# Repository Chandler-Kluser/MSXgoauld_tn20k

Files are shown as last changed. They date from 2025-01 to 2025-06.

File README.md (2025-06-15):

# MSXgoauld_tn20k
MSX Goa'uld board with Tang Nano 20k

Pantallazo
goauld_smd

MSX2+ engine in Z80 socket. It turns one MSX into an MSX2+ by replacing Z80 processor. FPGA in board contains: 
* Z80
* V9958 with hdmi output
* MSX2+ BIOS
* 4MB mapper
* RTC
* PSG through hdmi
* PPI Key Clicks through hdmi
* OPLL through hdmi
* SCC (audio only) through hdmi
* USB Keyboard with [MSX Goa'uld Friend](https://github.com/Chandler-Kluser/msx-goauld-friend)
* Scanlines toggling with [MSX Goa'uld Friend](https://github.com/Chandler-Kluser/msx-goauld-friend)
* On Screen Display (OSD) toggling with [MSX Goa'uld Friend](https://github.com/Chandler-Kluser/msx-goauld-friend)

## How it works
Logic acts on bus control signals so that internal devices inside fpga take priority over external devices. 

Esquema

Mind Revision 2, 4 and 4.1 uses 74LVC245 in U5. Although their technical information tells they require 3.3V to operate, they are also 5V tolerant. This has been tested and considered safe. Check https://github.com/jabadiagm/MSXgoauld_tn20k/issues/15 for more information. Revisions 2, 4 are outdated and kept for reference only. 

## Revision 2 Board

Revision 2 uses SOIC-20 for 74HCT373 and 74LVC245 ICs, which are smaller:



## Revision 4 Board

Revision 4 uses TSSOP-20 ICs, to get an even smaller footprint:


## Revision 4.1 Board

Revision 4.1 is an improvement of Revision 4, with no external regulator and UART Headers to use with [MSX Goa'uld Friend](https://github.com/Chandler-Kluser/msx-goauld-friend)

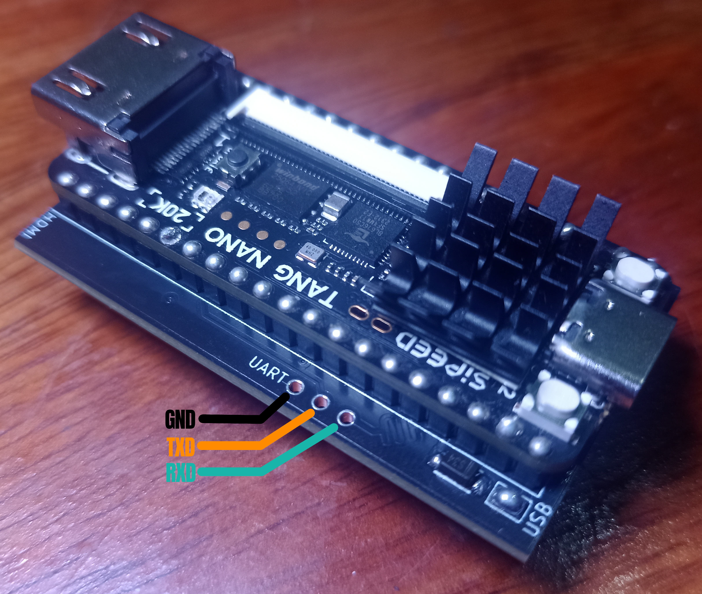
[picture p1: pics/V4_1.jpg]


## Slot map

Slot map

Mapper can be relocated to slots 1, 2, or 3 using config menu.

## Update from previous hardware
* Replace U1, U2 -> 74HC373, U5 -> 74HC245
* Solder a 10K resistor array to data bus lines, pulled up to 5V
Array

## SCC audio
SCC is located in Slot 0-2 to use with sofarun, using these settings:

ext_scc

## Configuration
Config menu is showed pressing g during MSX logo. New improved menu is created by [nataliapc](https://github.com/nataliapc/msx_goauld_settings_menu)

Config

* Enable Mapper: On by default. Disable when having compatibility issues or to use a different mapper
* Mapper Slot: 0 by default. Change to 1-3 to get mapper in a not expanded slot (best compatibility). Physical slot will be disabled
* Slot 1 Ghost SCC: Off by default. Enable to get sound from an SCC cartridge located in slot 1
* Enable Scanlines: On by default. Disable to get a clean hdmi picture
* Save & Exit: store new config and continue, changes in mapper settings will be effective after pressing reset
* Save & Reset: store new config and make software reset, changes will be immediate

## Slots dance
Goa'uld has four internal slots available. As with other modules, internal slots take priority over physical ones. This means that when a device is using internal slot n, then physical slot n is disabled  and any cartridge in that slot will not be detected. 
By default, BIOS and mapper occupy internal slot 0, leaving physical slots 1 to 3 available for cartridges. However, this default layout can cause compatibility issues with some software, such as tape games. 
To resolve these issues, you can move the mapper from expanded slot 0 to one of the non-expanded internal slots (1, 2, or 3). This adjustment can solve many compatibility problems.

## Known issues
* Reset from config menu is not compatible with some hardware. Use physical reset button when possible
* Multimente: shows garbage characters. Move internal mapper to slots 1, 2 or 3
* Tape games fail: move internal mapper to slots 1, 2 or 3
* Noises when loading a rom with sofarun: change sofarun settings to use mapper for that rom
* Carnivore C2 software reset is not compatible with goa'uld

> [!WARNING]
> Not yet fully working on all MSX!
>

### Tips
* Get integrated circuits from trusted sources
* Use a heatsink when possible
* Use turned pins in header to avoid damages in Z80 socket
turned header
* Board is sensitive to dirty electrical contacts, way more than Z80. Keep cartridge & Z80 socket contacts clean
* When soldering headers, start with the inner one (Z80)

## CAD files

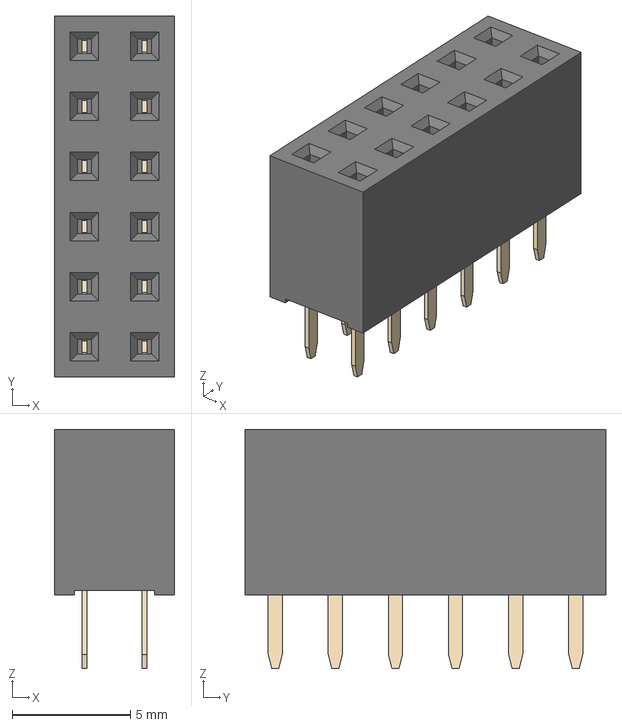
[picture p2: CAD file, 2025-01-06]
kicad/v1_smd/librerias/3D/PinSocket_2x06_P2.54mm_Vertical.step
5.08 x 15.2 x 10.1 mm

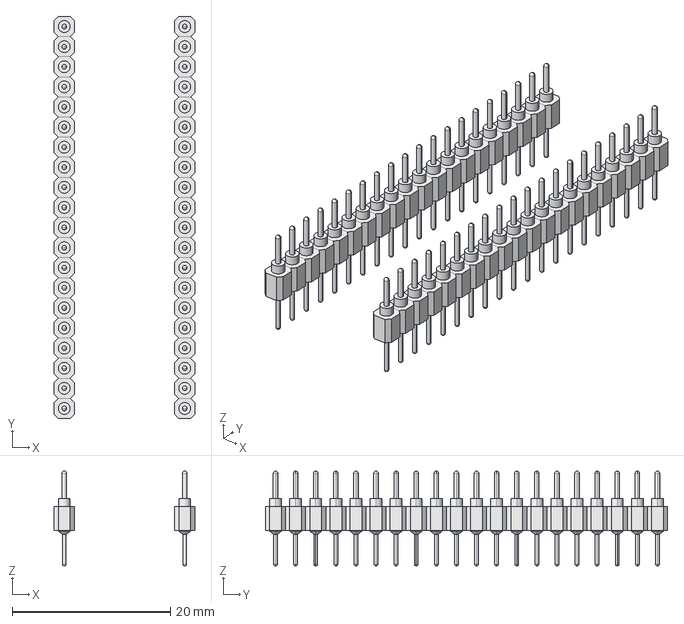
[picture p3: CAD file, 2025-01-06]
kicad/v1_smd/librerias/3D/Z80_PINHEADER.step
17.8 x 50.8 x 12.0 mm
Header-Male-round x 40

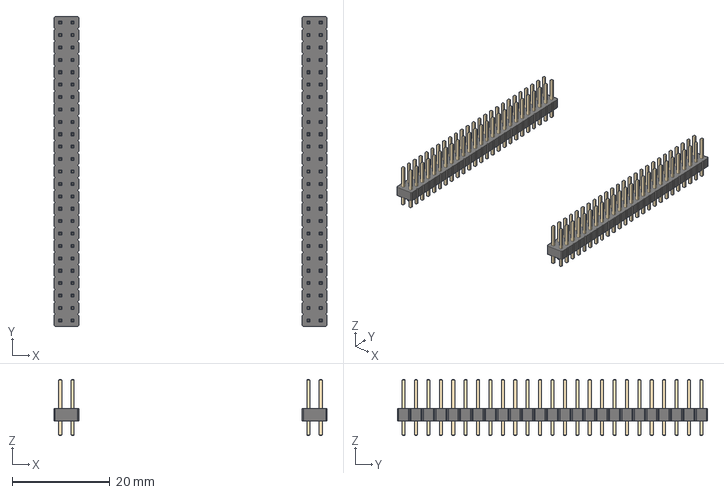
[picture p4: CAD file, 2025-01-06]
kicad/v1_smd/librerias/3D/Qmtech_xc7a15t_35t.step
55.9 x 63.5 x 11.5 mm
PinHeader_2x25_P254mm_Vertical x 2

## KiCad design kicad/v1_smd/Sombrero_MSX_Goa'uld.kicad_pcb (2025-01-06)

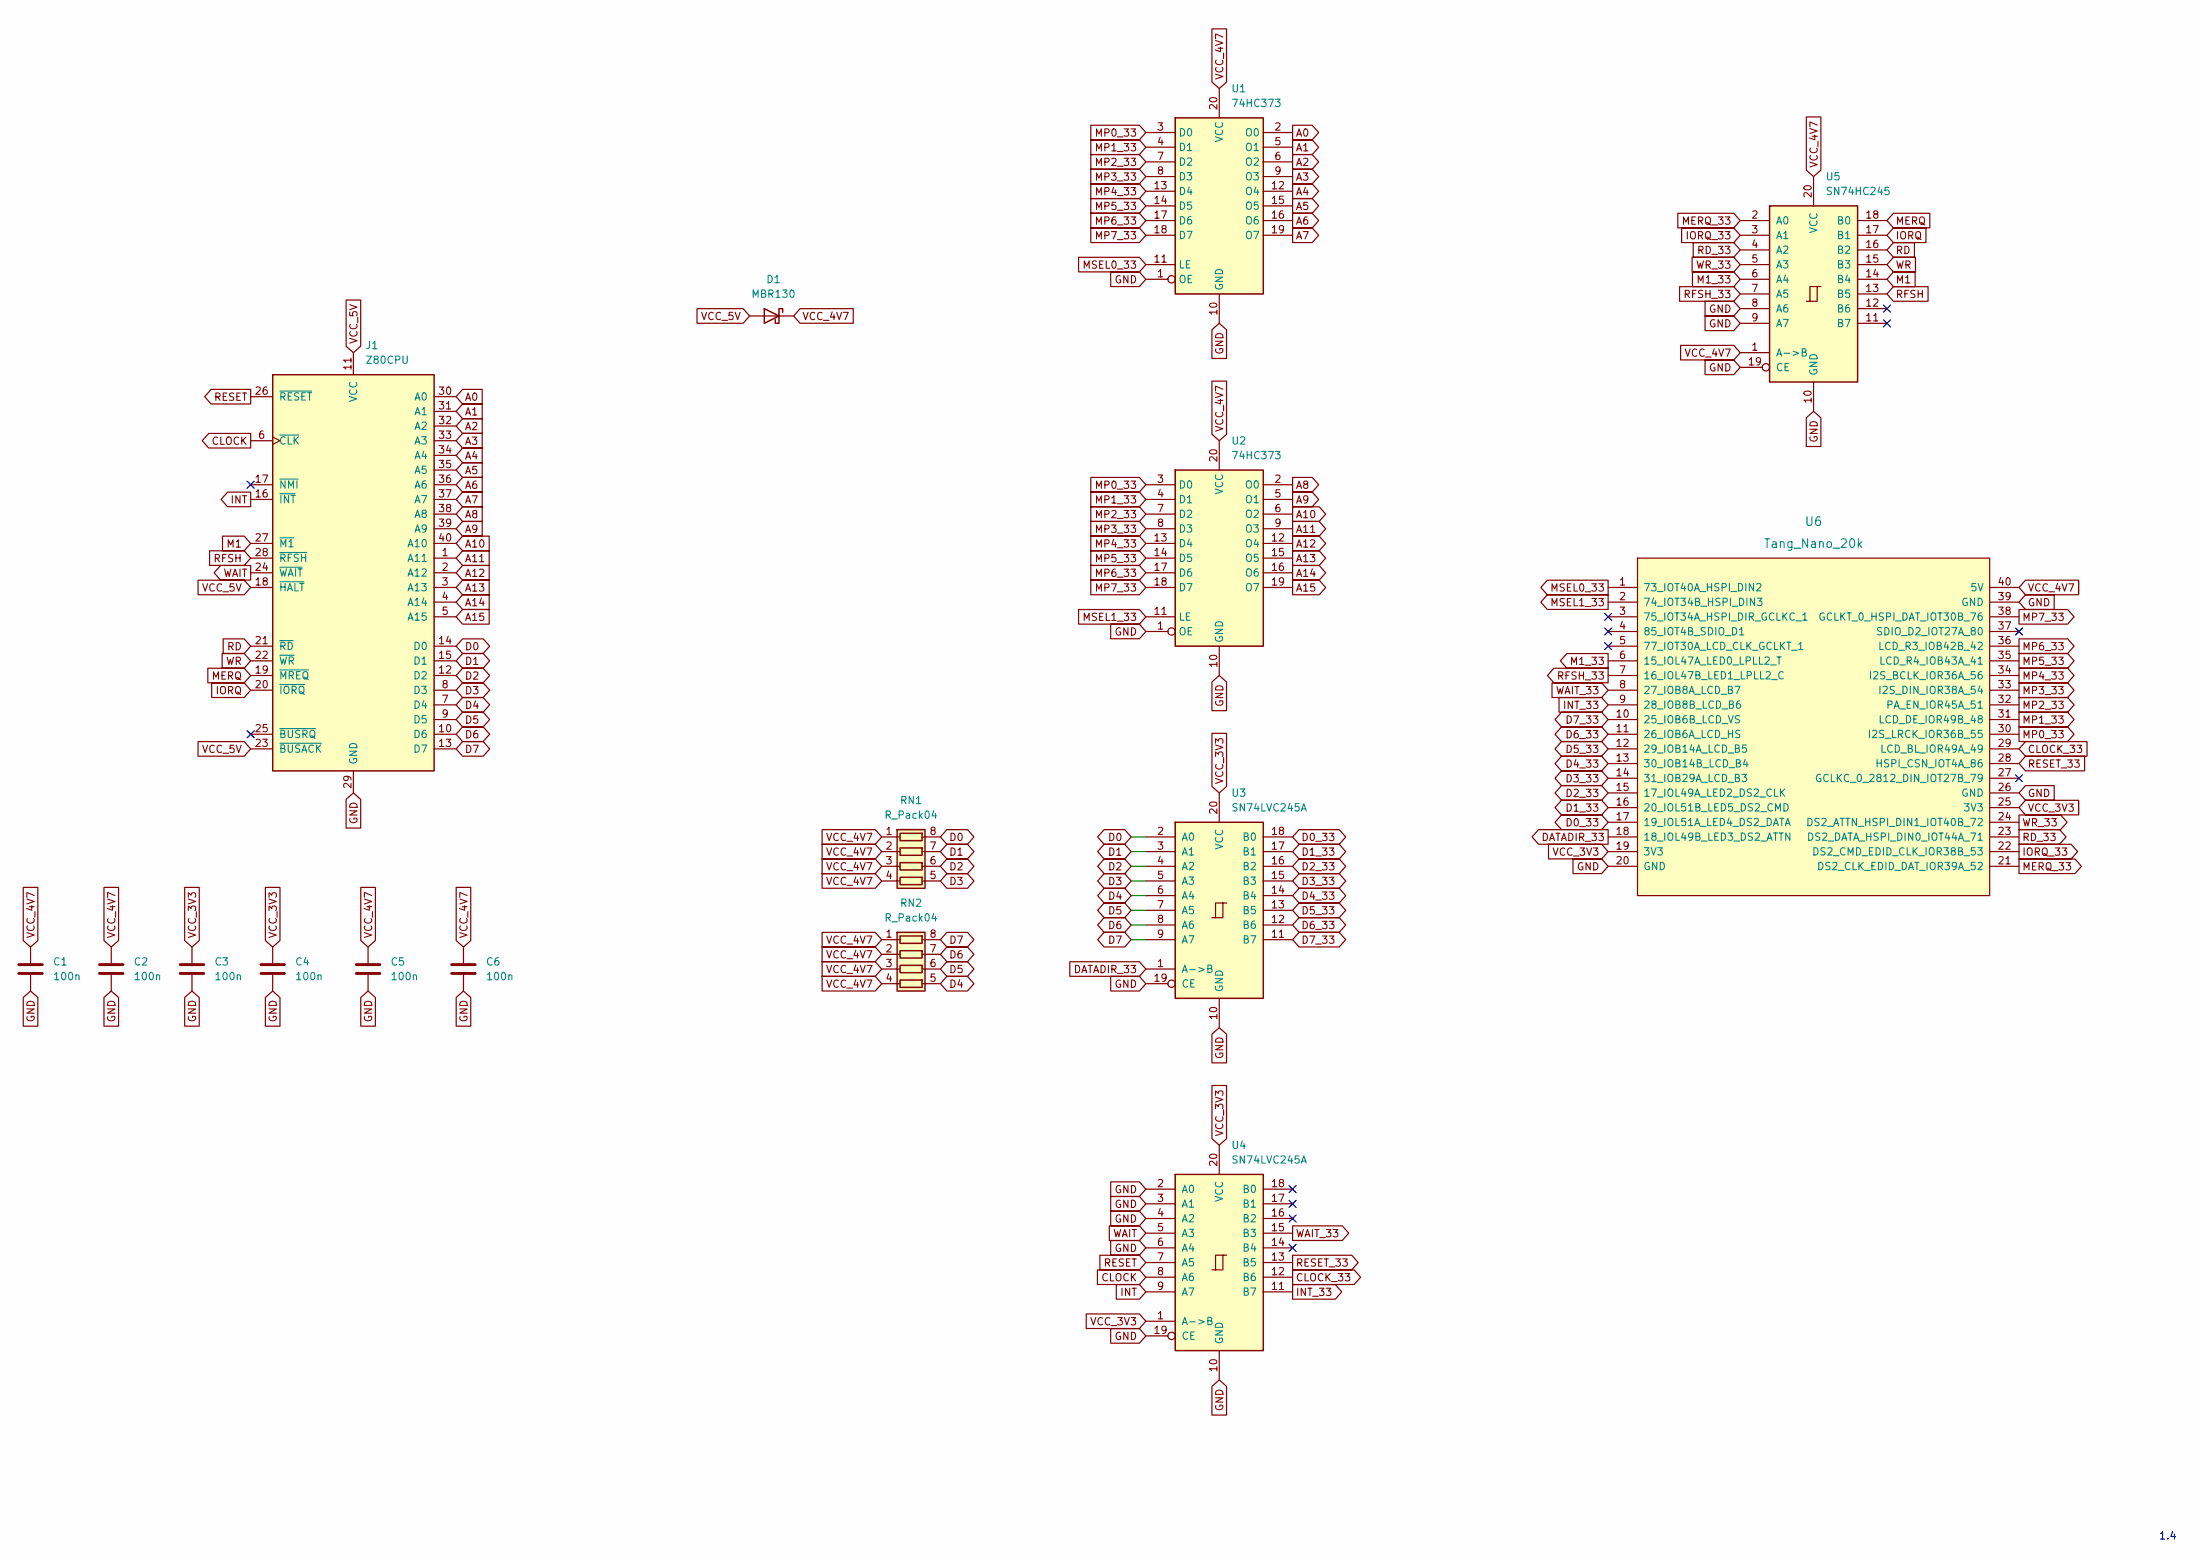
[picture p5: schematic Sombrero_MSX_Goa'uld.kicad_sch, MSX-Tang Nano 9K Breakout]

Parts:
C1, C2, C3, C4, C5, C6: 100n; C_0805_2012Metric
D1: MBR130; D_SOD-123
J1: Z80CPU; DIP-40_W15.24mm_Socket
RN1, RN2: R_Pack04; R_Array_Convex_4x0603
U1, U2: 74HC373; TSSOP-20_4.4x6.5mm_P0.65mm
U3, U4: SN74LVC245A; TSSOP-20_4.4x6.5mm_P0.65mm
U5: SN74HC245; TSSOP-20_4.4x6.5mm_P0.65mm
U6: Tang_Nano_20k

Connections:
A0: J1.30 (A0), U1.2 (O0)
A1: J1.31 (A1), U1.5 (O1)
A2: J1.32 (A2), U1.6 (O2)
A3: J1.33 (A3), U1.9 (O3)
A4: J1.34 (A4), U1.12 (O4)
A5: J1.35 (A5), U1.15 (O5)
A6: J1.36 (A6), U1.16 (O6)
A7: J1.37 (A7), U1.19 (O7)
A8: J1.38 (A8), U2.2 (O0)
A9: J1.39 (A9), U2.5 (O1)
A10: J1.40 (A10), U2.6 (O2)
A11: J1.1 (A11), U2.9 (O3)
A12: J1.2 (A12), U2.12 (O4)
A13: J1.3 (A13), U2.15 (O5)
A14: J1.4 (A14), U2.16 (O6)
A15: J1.5 (A15), U2.19 (O7)
CLOCK: J1.6 (~CLK), U4.8 (A6)
CLOCK_33: U4.12 (B6), U6.29 (LCD_BL_IOR49A_49)
D0: J1.14 (D0), RN1.8 (R1.2), U3.2 (A0)
D0_33: U3.18 (B0), U6.17 (19_IOL51A_LED4_DS2_DATA)
D1: J1.15 (D1), RN1.7 (R2.2), U3.3 (A1)
D1_33: U3.17 (B1), U6.16 (20_IOL51B_LED5_DS2_CMD)
D2: J1.12 (D2), RN1.6 (R3.2), U3.4 (A2)
D2_33: U3.16 (B2), U6.15 (17_IOL49A_LED2_DS2_CLK)
D3: J1.8 (D3), RN1.5 (R4.2), U3.5 (A3)
D3_33: U3.15 (B3), U6.14 (31_IOB29A_LCD_B3)
D4: J1.7 (D4), RN2.5 (R4.2), U3.6 (A4)
D4_33: U3.14 (B4), U6.13 (30_IOB14B_LCD_B4)
D5: J1.9 (D5), RN2.6 (R3.2), U3.7 (A5)
D5_33: U3.13 (B5), U6.12 (29_IOB14A_LCD_B5)
D6: J1.10 (D6), RN2.7 (R2.2), U3.8 (A6)
D6_33: U3.12 (B6), U6.11 (26_IOB6A_LCD_HS)
D7: J1.13 (D7), RN2.8 (R1.2), U3.9 (A7)
D7_33: U3.11 (B7), U6.10 (25_IOB6B_LCD_VS)
DATADIR_33: U3.1 (A->B), U6.18 (18_IOL49B_LED3_DS2_ATTN)
GND: C1.2, C2.2, C3.2, C4.2, C5.2, C6.2, J1.29 (GND), U1.1 (OE), U1.10 (GND), U2.1 (OE), U2.10 (GND), U3.10 (GND), U3.19 (CE), U4.2 (A0), U4.3 (A1), U4.4 (A2), U4.6 (A4), U4.10 (GND), U4.19 (CE), U5.8 (A6), U5.9 (A7), U5.10 (GND), U5.19 (CE), U6.20 (GND), U6.26 (GND), U6.39 (GND)
INT: J1.16 (~INT), U4.9 (A7)
INT_33: U4.11 (B7), U6.9 (28_IOB8B_LCD_B6)
IORQ: J1.20 (~IORQ), U5.17 (B1)
IORQ_33: U5.3 (A1), U6.22 (DS2_CMD_EDID_CLK_IOR38B_53)
M1: J1.27 (~M1), U5.14 (B4)
M1_33: U5.6 (A4), U6.6 (15_IOL47A_LED0_LPLL2_T)
MERQ: J1.19 (~MREQ), U5.18 (B0)
MERQ_33: U5.2 (A0), U6.21 (DS2_CLK_EDID_DAT_IOR39A_52)
MP0_33: U1.3 (D0), U2.3 (D0), U6.30 (I2S_LRCK_IOR36B_55)
MP1_33: U1.4 (D1), U2.4 (D1), U6.31 (LCD_DE_IOR49B_48)
MP2_33: U1.7 (D2), U2.7 (D2), U6.32 (PA_EN_IOR45A_51)
MP3_33: U1.8 (D3), U2.8 (D3), U6.33 (I2S_DIN_IOR38A_54)
MP4_33: U1.13 (D4), U2.13 (D4), U6.34 (I2S_BCLK_IOR36A_56)
MP5_33: U1.14 (D5), U2.14 (D5), U6.35 (LCD_R4_IOB43A_41)
MP6_33: U1.17 (D6), U2.17 (D6), U6.36 (LCD_R3_IOB42B_42)
MP7_33: U1.18 (D7), U2.18 (D7), U6.38 (GCLKT_0_HSPI_DAT_IOT30B_76)
MSEL0_33: U1.11 (LE), U6.1 (73_IOT40A_HSPI_DIN2)
MSEL1_33: U2.11 (LE), U6.2 (74_IOT34B_HSPI_DIN3)
RD: J1.21 (~RD), U5.16 (B2)
RD_33: U5.4 (A2), U6.23 (DS2_DATA_HSPI_DIN0_IOT44A_71)
RESET: J1.26 (~RESET), U4.7 (A5)
RESET_33: U4.13 (B5), U6.28 (HSPI_CSN_IOT4A_86)
RFSH: J1.28 (~RFSH), U5.13 (B5)
RFSH_33: U5.7 (A5), U6.7 (16_IOL47B_LED1_LPLL2_C)
VCC_3V3: C3.1, C4.1, U3.20 (VCC), U4.1 (A->B), U4.20 (VCC), U6.19 (3V3), U6.25 (3V3)
VCC_4V7: C1.1, C2.1, C5.1, C6.1, D1.1 (K), RN1.1 (R1.1), RN1.2 (R2.1), RN1.3 (R3.1), RN1.4 (R4.1), RN2.1 (R1.1), RN2.2 (R2.1), RN2.3 (R3.1), RN2.4 (R4.1), U1.20 (VCC), U2.20 (VCC), U5.1 (A->B), U5.20 (VCC), U6.40 (5V)
VCC_5V: D1.2 (A), J1.11 (VCC), J1.18 (~HALT), J1.23 (~BUSACK)
WAIT: J1.24 (~WAIT), U4.5 (A3)
WAIT_33: U4.15 (B3), U6.8 (27_IOB8A_LCD_B7)
WR: J1.22 (~WR), U5.15 (B3)
WR_33: U5.5 (A3), U6.24 (DS2_ATTN_HSPI_DIN1_IOT40B_72)

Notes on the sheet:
1.4

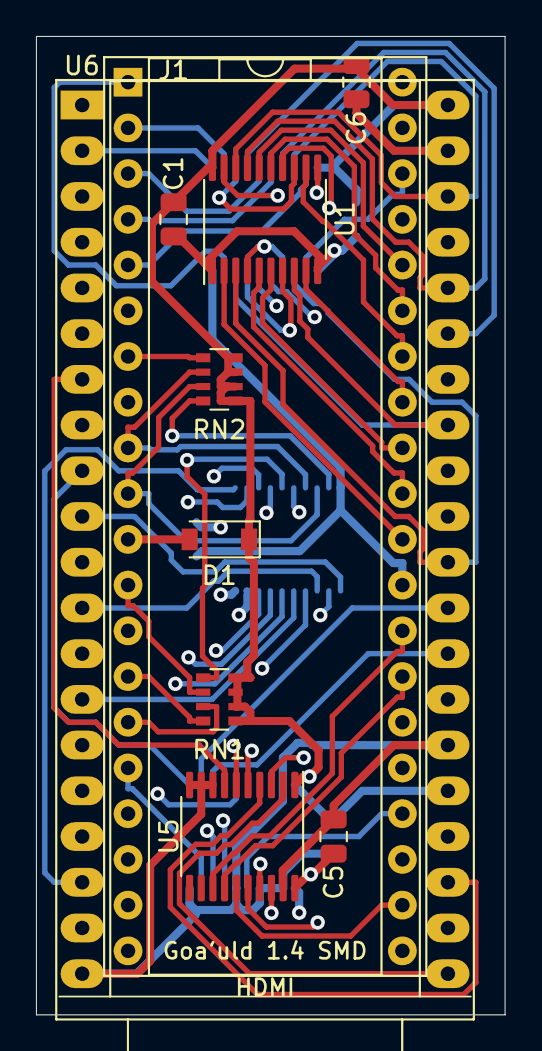
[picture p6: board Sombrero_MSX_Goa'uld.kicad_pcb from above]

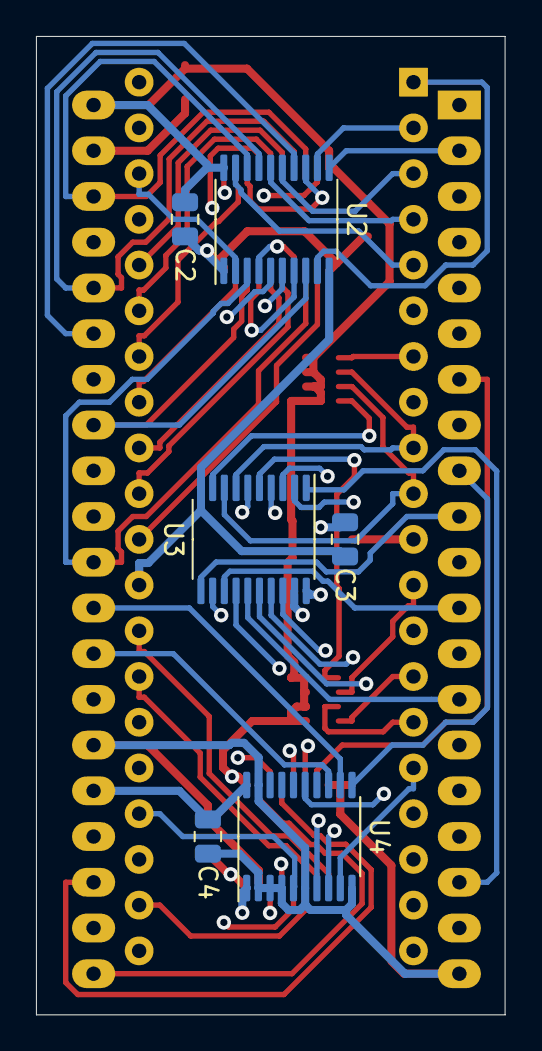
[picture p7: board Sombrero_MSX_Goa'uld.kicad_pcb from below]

Board: 4 copper layers, 26.0 x 54.4 mm, 16 parts (6 on the bottom side), 67 nets.

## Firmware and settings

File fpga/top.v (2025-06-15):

`define ENABLE_V9958
`define ENABLE_BIOS
`define ENABLE_SOUND //v9958, bios required
`define ENABLE_MAPPER //bios required
`define ENABLE_CONFIG
`define UART_PORT
`define PPI_KEYBEEP

module top(
    input ex_clk_27m,
    input s1,
    input s2,

    input ex_bus_wait_n,
    input ex_bus_int_n,
    input ex_bus_reset_n,
    input ex_bus_clk_3m6,

    inout [7:0] ex_bus_data,

    output [1:0] ex_msel,
    output ex_bus_m1_n,
    output ex_bus_rfsh_n,
    output reg ex_bus_mreq_n,
    output reg ex_bus_iorq_n,
    output reg ex_bus_rd_n,
    output reg ex_bus_wr_n,

    output ex_bus_data_reverse_n,
    output ex_bus_data_reverse,
    output [7:0] ex_bus_mp,

    //hdmi out
    output [2:0] data_p,
    output [2:0] data_n,
    output clk_p,
    output clk_n,
`ifdef UART_PORT
    //uart
    output uart0_tx,
    input uart0_rx,
    // output uart1_tx,
    // input uart1_rx,
`endif

    // Magic ports for SDRAM to be inferred
    output O_sdram_clk,
    output O_sdram_cke,
    output O_sdram_cs_n, // chip select
    output O_sdram_cas_n, // columns address select
    output O_sdram_ras_n, // row address select
    output O_sdram_wen_n, // write enable
    inout [31:0] IO_sdram_dq, // 32 bit bidirectional data bus
    output [10:0] O_sdram_addr, // 11 bit multiplexed address bus
    output [1:0] O_sdram_ba, // two banks
    output [3:0] O_sdram_dqm, // 32/4

    output SLTSL3

);

initial begin
`ifdef UART_PORT
    ppi_port_b <= 8'hFF;
    ppi_port_c <= 8'h00;
`endif
end

`ifdef PPI_KEYBEEP
    reg keybeep;
`endif

    assign SLTSL3 = bus_mreq_disable ^ bus_iorq_disable ^ xffh ^ xffl ^ mapper_read ^ exp_slot3_req_r ^ bios_req ^ subrom_req ^ vdp_csr_n;

    //clocks
    wire clk_108m;
    wire clk_108m_n;
    CLK_108P clk_main (
        .clkout(clk_108m), //output clkout
        .lock(), //output lock
        .clkoutp(clk_108m_n), //output clkoutp
        .reset(0), //input reset
        .clkin(ex_clk_27m) //input clkin
    );

    wire clk_enable_27m;
    wire clk_enable_54m;
    reg [1:0] cnt_clk_enable_27m;
    always @ (posedge clk_108m) begin
        cnt_clk_enable_27m <= cnt_clk_enable_27m + 1;
    end
    assign clk_enable_27m = ( cnt_clk_enable_27m == 2'b00 ) ? 1: 0;
    assign clk_enable_54m = ( cnt_clk_enable_27m[0] == 1 ) ? 1: 0;

    wire clk_27m;
    BUFG buf1 (
        .O(clk_27m),
        .I(ex_clk_27m)
    );

//    wire clk_54m;
//    wire clk_54m_buf;
//    Gowin_rPLL pll(
//        .clkout(clk_54m_buf), //output clkout
//        .clkin(ex_clk_27m) //input clkin
//    );

//    BUFG buf2(
//        .O(clk_54m),
//        .I(clk_54m_buf)
//    );

    wire bus_clk_3m6;
    PINFILTER dn1(
        .clk(clk_108m),
        .reset_n(1),
        .din(ex_bus_clk_3m6),
        .dout(bus_clk_3m6)
    );

    wire clk_enable_3m6;
    wire clk_falling_3m6;
    reg bus_clk_3m6_prev;
    always @ (posedge clk_108m) begin
        bus_clk_3m6_prev <= bus_clk_3m6;
    end
    assign clk_enable_3m6 = (bus_clk_3m6_prev == 0 && bus_clk_3m6 == 1);
    assign clk_falling_3m6 = (bus_clk_3m6_prev == 1 && bus_clk_3m6 == 0);

    wire bus_wait_n;
    PINFILTER dn2(
        .clk(clk_108m),
        .reset_n(1),
        .din(ex_bus_wait_n),
        .dout(bus_wait_n)
    );

    wire bus_reset_n;
    PINFILTER dn3(
        .clk(clk_108m),
        .reset_n(1),
`ifdef UART_PORT
        // TO DO:
        // this uart reset logic is not working
        .din(ex_bus_reset_n & ~config_reset & reset4_n_ff),
`else
        .din(ex_bus_reset_n & ~config_reset),
`endif
        .dout(bus_reset_n)
    );

    wire int_n;
//    PINFILTER dn4(
//        .clk(clk_108m),
//        .reset_n(1),
//        .din(ex_bus_int_n),
//        .dout(bus_int_n)
//    );
    denoise dn4 (
		.data_in (ex_bus_int_n),
		.clock(clk_108m),
		.data_out (bus_int_n)
    );

    reg [7:0] bus_data;
//    genvar i;
//    generate
//        for (i = 0; i <= 7; i++)
//        begin: bus_din
//            PINFILTER dn(
//                .clk(clk_108m),
//                .reset_n(1),
//                .din(ex_bus_data[i]),
//                .dout(bus_data[i])
//            );
//            denoise2 dn (
//                .data_in (ex_bus_data[i]),
//                .clock(clk_108m),
//                .data_out (bus_data[i])
//            );
//        end
//    endgenerate

    always @ (posedge clk_108m) begin
        bus_data <= ex_bus_data;
    end
`ifdef UART_PORT
    // uart
    uart uart0(
        .clk(clk_27m),
        .rst(~bus_reset_n),
        .uart0_rx(uart0_rx),
        .uart0_tx(uart0_tx),
        .reset4_n_ff(reset4_n_ff),
        .OSD(OSD),
        .SCANLINES(SCANLINES),
        .ppi_port_b(ppi_port_b),
        .ppi_port_c(ppi_port_c),
        .SHIFT_UP(SHIFT_UP)
    );
`endif

    //startup logic
    reg reset1_n_ff;
    reg reset2_n_ff;
    reg reset3_n_ff;
    wire reset1_n;
    wire reset2_n;
    wire reset3_n;

    reg [15:0] counter_reset = 0;
    reg [1:0] rst_seq;
    reg rst_step;

    always @ (posedge ex_clk_27m or negedge bus_reset_n) begin
        if (bus_reset_n == 0) begin
            rst_step <= 0;
            counter_reset <= 0;
        end
        else begin
            rst_step <= 0;
            if ( counter_reset <= 16'h8000 ) 
                counter_reset <= counter_reset + 1;
            else begin
                rst_step <= 1;
                counter_reset <= 0;
            end
        end
    end

    always @ (posedge ex_clk_27m or negedge bus_reset_n or posedge sdram_fail) begin
        if (bus_reset_n == 0 || sdram_fail == 1) begin
            rst_seq <= 2'b00;
            reset1_n_ff <= 0;
            reset2_n_ff <= 0;
            reset3_n_ff <= 0;
        end
        else begin
            case ( rst_seq )
                2'b00: 
                    if (rst_step == 1 ) begin
                        reset1_n_ff <= 1;
                        rst_seq <= 2'b01;
                    end
                2'b01: 
                    if (rst_step == 1) begin
                        reset2_n_ff <= 1;
                        rst_seq <= 2'b10;
                    end
                2'b10:
                    if (rst_step == 1) begin
                        reset3_n_ff <= 1;
                        rst_seq <= 2'b11;
                    end
            endcase
        end
    end
    assign reset1_n = reset1_n_ff;
    assign reset2_n = reset2_n_ff;
    assign reset3_n = reset3_n_ff;

    //bus demux
    reg [1:0] msel;
    reg [7:0] bus_mp;
//    reg msel_ff = 0;
    reg [4:0] mp_cnt;
    wire [15:0] bus_addr;
    assign ex_msel = msel;
    assign ex_bus_mp = bus_mp;
//    assign msel = { msel_ff, ~ msel_ff };
//    assign bus_mp = ( msel[1] == 1 ) ? bus_addr[15:8] : bus_addr[7:0];
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

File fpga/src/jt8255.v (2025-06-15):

/*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
    Author: Jose Tejada Gomez. Twitter: @topapate
    Version: 1.0
    Date: 28-3-2021
 */

module jt8255(
    input               rst,
    input               clk,

    // CPU interface
    input       [1:0]   addr,
    input       [7:0]   din,
    output reg  [7:0]   dout,
    input               rdn,
    input               wrn,
    input               csn,

    // External pins to peripherals
    input       [7:0]   porta_din,
    input       [7:0]   portb_din,
    input       [7:0]   portc_din,

    output reg  [7:0]   porta_dout,
    output reg  [7:0]   portb_dout,
    output      [7:0]   portc_dout
);

localparam ISINA=4, ISINB=1, ISINCL=0, ISINCH=3; // Control word bits
localparam INTRA=3, OBFA=7, ACKA=6, STBA=4, IBFA=5, // PC bits, mode 2
           INTRB=0, OBFB=1, ACKB=2, STBB=2, IBFB=1;

localparam INTEA_OBF=6, INTEA_IBF=4, INTEB=2;

reg  [6:0] ctrl;
reg  [7:0] latch_a, latch_b, latch_c;

wire       mode_b,
           isin_a, isin_b, isin_cl, isin_ch; // is input a,b,c...
wire [1:0] mode_a;

wire       write, read;
reg        last_write, last_read;

reg        inte_a_obf, inte_a_ibf, inte_b;
wire       acka, ackb, stba, stbb;

reg        last_acka, last_ackb, last_stba;
wire       last_stbb;

assign read   = !rdn && !csn;
assign write  = !wrn && !csn;
assign mode_b = ctrl[2];
assign mode_a = ctrl[6:5];

assign isin_a  = ctrl[ISINA];
assign isin_b  = ctrl[ISINB];
assign isin_cl = ctrl[ISINCL];
assign isin_ch = ctrl[ISINCH];

assign acka    = portc_din[ACKA];
assign stba    = portc_din[STBA];
assign ackb    = portc_din[ACKB];
assign stbb    = portc_din[STBB]; // this is the same as ackb
assign last_stbb = last_ackb;


// Mode control
always @(posedge clk, posedge rst) begin
    if( rst ) begin
        ctrl       <= 7'h1b;
        latch_a    <= 8'hff;
        latch_b    <= 8'hff;
        latch_c    <= 8'hff;

        inte_a_ibf <= 0;
        inte_a_obf <= 0;
        inte_b     <= 0;

        last_write <= 0;
        last_acka  <= 0;
        last_ackb  <= 0;
        last_stba  <= 0;
    end else begin
        last_write <= write;
        last_acka  <= acka;
        last_ackb  <= ackb;
        last_stba  <= stba;

//        if( !write && last_write ) begin
        if( write ) begin		  //Changed
            case( addr )
                2'd0: begin // Port A
                    if( !isin_a || mode_a[1] ) begin
                        latch_a <= din; // A is an output
                        if( mode_a!=0 ) begin
                            latch_c[OBFA] <= 0;
                            if(inte_a_obf) latch_c[INTRA] <= 0;  // interrupt pin
                        end
                    end
                end
                2'd1: begin // Port B
                    if( !isin_b ) begin
                        latch_b <= din; // B is an output
                        if( mode_b ) begin
                            latch_c[OBFB] <= 0;
                            if(inte_b) latch_c[INTRB] <= 0;  // interrupt pin
                        end
                    end                end
                2'd2: begin
                    if( mode_b )
                        inte_b <= din[INTEB];
                    else
                        latch_c[2:0] <= din[2:0];

                    if( (mode_a==0 || (mode_a[0]&&isin_a)) )
                        latch_c[7:6] <= din[7:6];

                    if( mode_a==0 || (mode_a[0]&&!isin_a) )
                        latch_c[5:4] <= din[5:4];

                    if( mode_a==0 )
                        latch_c[3] <= din[3];

                    if( mode_a[1] || (mode_a[0] && isin_a) )
                        inte_a_ibf <= din[INTEA_IBF];
                    if( mode_a[1] || (mode_a[0] && !isin_a) )
                        inte_a_obf <= din[INTEA_OBF];
                end
                2'd3: begin
                    if( din[7] ) begin
                        ctrl <= din[6:0];
                        if( !din[ISINCL] ) latch_c[3:0] <= 0;
                        if( !din[ISINCH] ) latch_c[7:4] <= 0;
                        if( !din[ISINB]  ) latch_b <= 0;
                        if( !din[ISINA]  ) latch_a <= 0;
                        inte_a_ibf <= 0;
                        inte_a_obf <= 0;
                        inte_b     <= 0;
                        if( din[2] ) begin
                            latch_c[IBFB] <= ~din[ISINB]; // start with safe IBF/OBF signals
                            latch_c[INTRB]<= ~din[ISINB];
                        end
                        if( din[6:5]!=0 ) begin
                            latch_c[IBFA] <= 0;
                            latch_c[OBFA] <= 1;
                            latch_c[INTRA]<= 0;
                        end
                    end else begin
                        latch_c[ din[3:1] ] <= din[0];
								if( din[3:1]==INTEA_OBF ) inte_a_obf <= din[0];
								if( din[3:1]==INTEA_IBF ) inte_a_ibf <= din[0];
								if( din[3:1]==INTEB ) inte_b <= din[0];
                    end
                end
            endcase
        end else begin
            // Input Buffer Full
            if( mode_b && isin_b && stbb && !last_stbb ) begin
                latch_c[IBFB] <= 1;
                if( inte_b ) latch_c[INTRB] <= 1;
            end
            if( (mode_a[1] || (mode_a[0] && isin_a)) && stba && !last_stba ) begin
                latch_c[IBFA] <= 1;
                if( inte_a_ibf ) latch_c[INTRA] <= 1;
            end

            if( mode_a!=2'd00 ) begin
					 // clears the interrupts
					 if(!inte_a_ibf && !inte_a_obf) latch_c[INTRA] <= 0; //Changed
					 // The peripheral reads
                if( (!isin_a || mode_a[1]) && acka && !last_acka ) begin
                    latch_c[INTRA] <= 1;
                    latch_c[OBFA]  <= 1;
                end
                // The CPU reads
                if( (isin_a || mode_a[1]) && read && !last_read && addr==2'd0 ) begin
                    latch_c[INTRA] <= 0;
                    latch_c[IBFA]  <= 0;
                end
            end
            if( mode_b ) begin
					 // clears the interrupts
					 if(!inte_b) latch_c[INTRB] <= 0; //Changed
                // The peripheral reads
                if( !isin_b && ackb && !last_ackb ) begin
                    latch_c[INTRB] <= 1;
                    latch_c[OBFB]  <= 1;
                end
                // The CPU reads
                if( isin_b && read && !last_read && addr==2'd1 ) begin
                    latch_c[INTRB] <= 0;
                    latch_c[IBFB]  <= 0;
                end
            end
        end
    end
end
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

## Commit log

2025-01-06 Added UART Scanlines + Keyboard Basic Buttons
    [MSX_Goauld_Rev4_1-B_Mask.gbs, MSX_Goauld_Rev4_1-B_Paste.gbp, MSX_Goauld_Rev4_1-B_Silkscreen.gbo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]
2025-01-06 Added Sample OSD
2025-01-06 Added UART Scanlines + Sample OSD + Basic Keyboard Keys
    [char.ods, device.cfg]
2025-06-15 Removed impl
    [device.cfg]

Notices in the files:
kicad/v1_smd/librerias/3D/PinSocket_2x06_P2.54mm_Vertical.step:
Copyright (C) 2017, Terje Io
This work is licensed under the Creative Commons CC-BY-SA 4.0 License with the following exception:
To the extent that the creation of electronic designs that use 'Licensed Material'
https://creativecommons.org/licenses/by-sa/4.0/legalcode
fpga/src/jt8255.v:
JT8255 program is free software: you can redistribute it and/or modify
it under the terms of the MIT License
